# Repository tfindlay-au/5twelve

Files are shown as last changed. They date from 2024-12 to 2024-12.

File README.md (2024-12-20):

# 5 Twelve

This project is a simple power adaptor - it draws 5v from the USB micro B port and provides 12v via the 10-pin header.

### Design

This board uses the minimum components and tried to standardise on 0603 packages

|Part number |Description |
|---|---|
|PAM2423 |DC-DC Converter |
|SDFL1608S6R8MTF |Sunlord Inductor |
|TSW-105-23-F-D-010 |2x5 pin header |
|USB3140-30-0230-1-C|USB Micro B port |
|SS34-E3/9AT |Circuit protection |
|VLMW1300-GS08 |LED indicator |

### Safety
The design uses a simple Shottky diode to protect the DC-DC converter

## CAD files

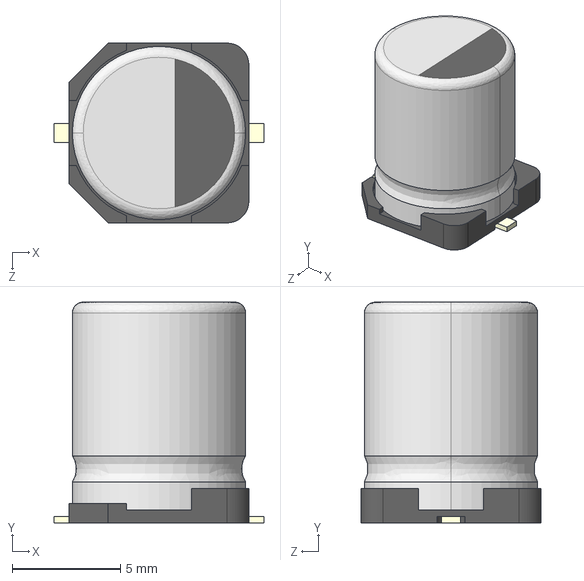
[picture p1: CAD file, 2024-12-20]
EEEHA1C471UP/EEEHA1C471UP.step
9.70 x 10.2 x 8.30 mm

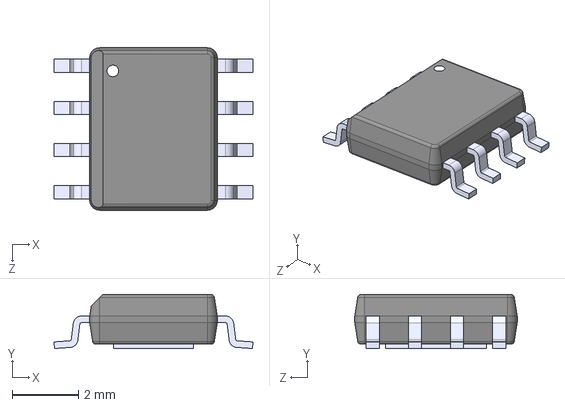
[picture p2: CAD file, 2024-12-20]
PAM2423/PAM2423AECADJR.step
6.00 x 1.63 x 4.90 mm

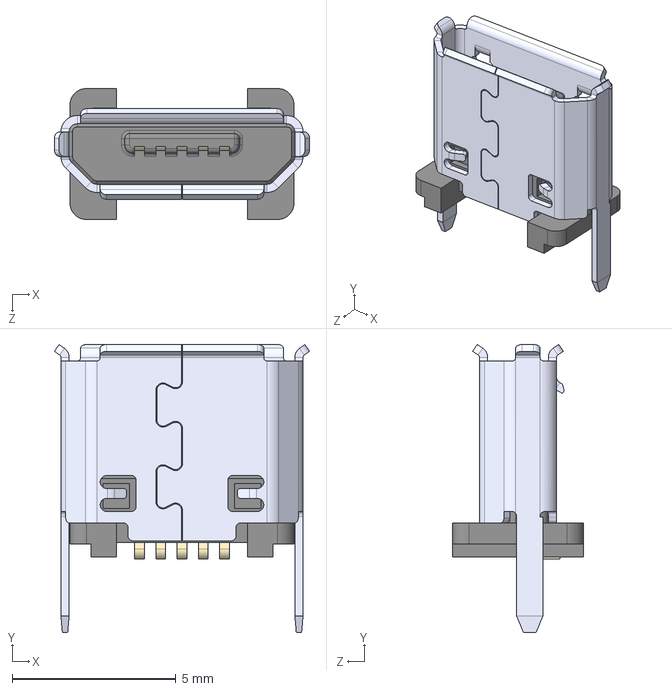
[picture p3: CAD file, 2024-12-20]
USB3140-30-0230-1-C_REVE1/USB3140-30-0230-1-C_REVE1.step
7.80 x 8.80 x 4.00 mm

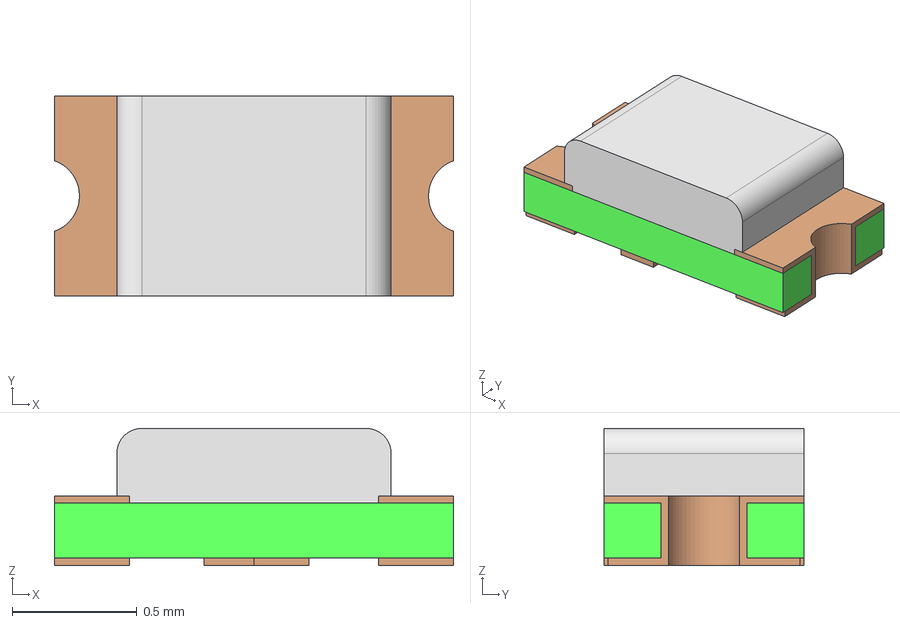
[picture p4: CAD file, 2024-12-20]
VLMW1300-GS08/80436ChipLED_SMD0603.stp
1.60 x 0.8 x 0.55 mm
6.541-5091-3D-2
2.200-5178-3D-2
2.200-5178-3D-3 x 2
2.200-5178-3D-4

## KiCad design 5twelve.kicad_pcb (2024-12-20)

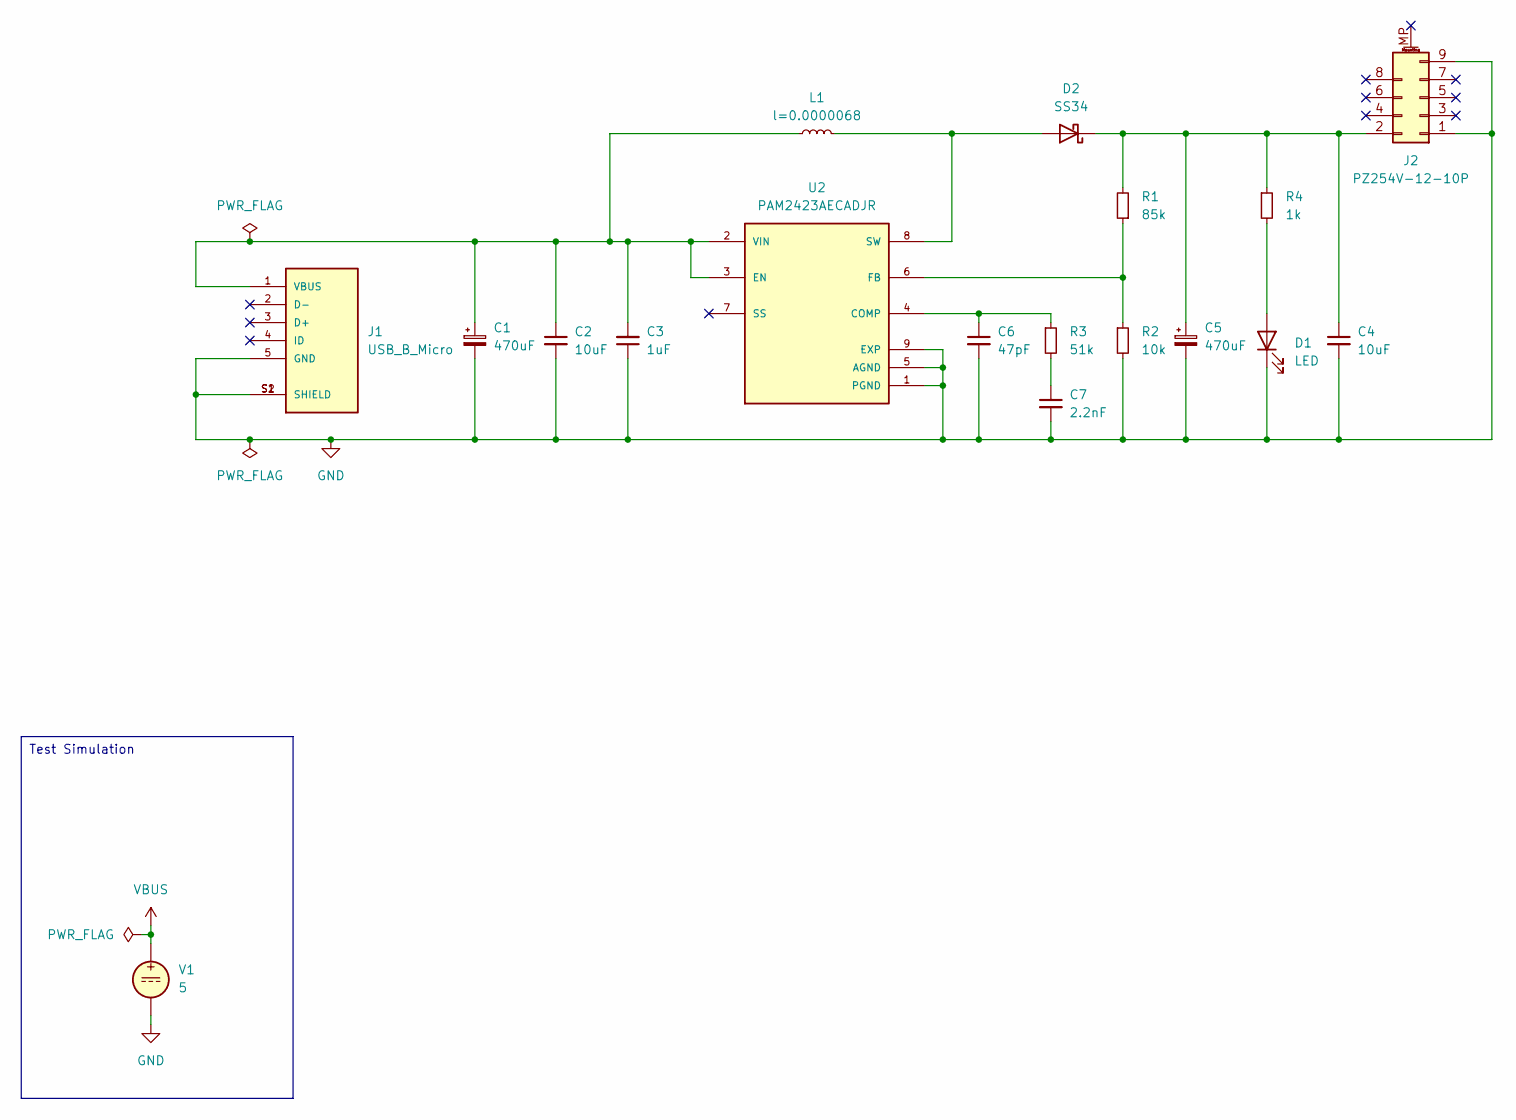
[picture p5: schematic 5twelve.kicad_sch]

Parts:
C1, C5: 470uF; C_Elec_8x10.2; LCSC C161936
C2, C4: 10uF; C_0603_1608Metric; LCSC C596327
C3: 1uF; C_0603_1608Metric; LCSC C14664
C6: 47pF; C_0603_1608Metric; LCSC C519392
C7: 2.2nF; C_0603_1608Metric; LCSC C309471
D1: LED; LED_0603_1608Metric; LCSC C413463
D2: SS34; D_SMC
J1: USB_B_Micro; GCT_USB3140-30-0230-1-C_REVE1; LCSC C6007483
J2: PZ254V-12-10P; PinHeader_2x05_P2.54mm_Vertical; LCSC C492422
L1: l=0.0000068; L_0603_1608Metric; LCSC C279872
R1: 85k; R_0603_1608Metric
R2: 10k; R_0603_1608Metric
R3: 51k; R_0603_1608Metric
R4: 1k; R_0603_1608Metric
U2: PAM2423AECADJR; SOIC127P600X163-9N
V1: 5

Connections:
GND: C1.2, C2.2, C3.1, C4.2, C5.2, C6.2, C7.2, D1.1 (K), J1.5 (GND), J1.S1 (SHIELD), J1.S2 (SHIELD), J2.1, J2.9, R2.2, U2.1 (PGND), U2.5 (AGND), U2.9 (EXP), V1.2
unnamed: C7.1, R3.2
unnamed: D1.2 (A), R4.2
unnamed: D2.2 (A), L1.2, U2.8 (SW)
unnamed: C4.1, C5.1, D2.1 (K), J2.2, R1.2, R4.1
unnamed: C1.1, C2.1, C3.2, J1.1 (VBUS), L1.1, U2.2 (VIN), U2.3 (EN)
unnamed: C6.1, R3.1, U2.4 (COMP)
unnamed: R1.1, R2.1, U2.6 (FB)

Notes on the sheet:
Test Simulation

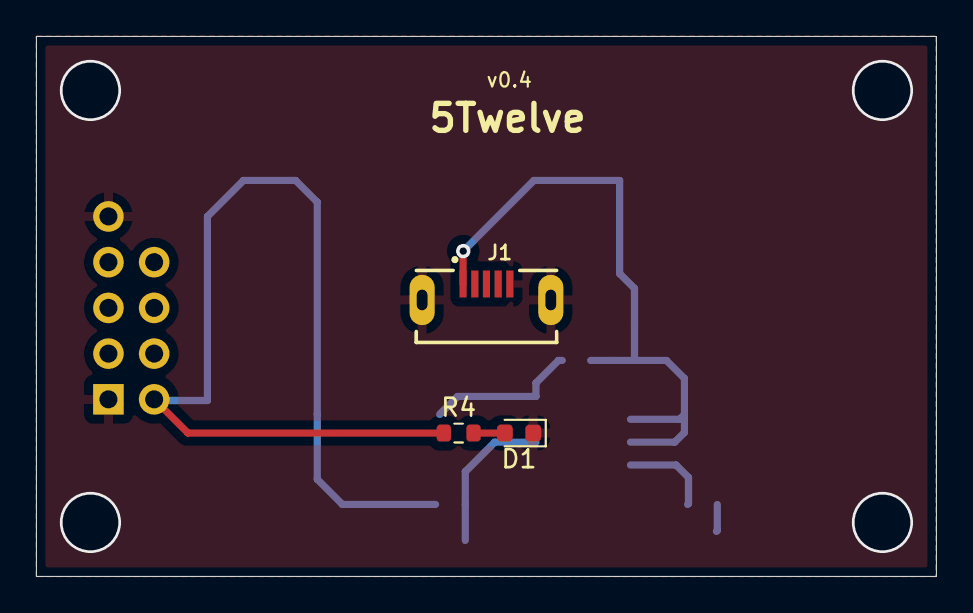
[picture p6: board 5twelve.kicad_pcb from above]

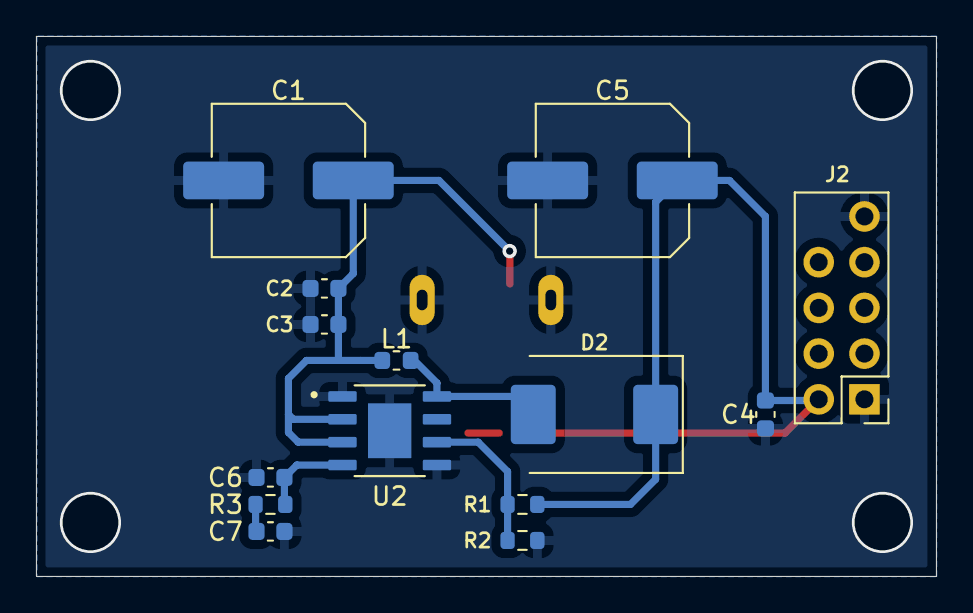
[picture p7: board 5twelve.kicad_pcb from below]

Board: 2 copper layers, 50.0 x 30.0 mm, 17 parts (14 on the bottom side), 8 nets.
